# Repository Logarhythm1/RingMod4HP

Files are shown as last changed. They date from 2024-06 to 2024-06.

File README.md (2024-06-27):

# RingMod4HP
CC-By-NC 4.0, 2024 (Non-commercial use permitted)

An AD633-based Ring Modulator in Eurorack format (4HP)

This is based on a design by Roman Sowa, who has kindly allowed me to share this implementation for anyone to build.

Built 1.0 Module Front

It's a great, clean-sounding ring modulator featuring the excellent AD633 IC.
The board is a pretty simple build, with mostly 0603 components. Two footprints are provided for the AD633 IC, and you should choose either DIP or soic package to place. No BOM is provided but it's pretty easy to see what's needed from the schematic. The specific hardware needed is:

- 3 Thonkiconn jacks
- 1 10k vertical 9mm pot
- 2 100k pots
- 2 micromini 3-way switches

Eagle 6 format schematic, board, and panel files are included.

Zip files containing the board and panel gerbers are also included.

Note: Images show the 1.0 version of the board and panel, which have a couple of errors that are corrected in the 1.1 versions presented here. Both were ordered from JLCPCB, with the panel as an "aluminum pcb." The panel came back with white paint and raw aluminum text, which is the inverse of what I expected but it works for me.

Version 1.0 board and panel:

Version 1.0 Board and Panel

Version 1.1 layout:

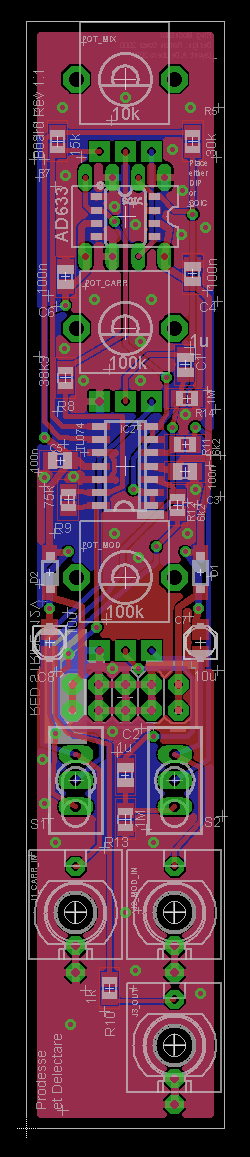
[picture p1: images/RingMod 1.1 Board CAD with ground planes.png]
Version 1.1 board


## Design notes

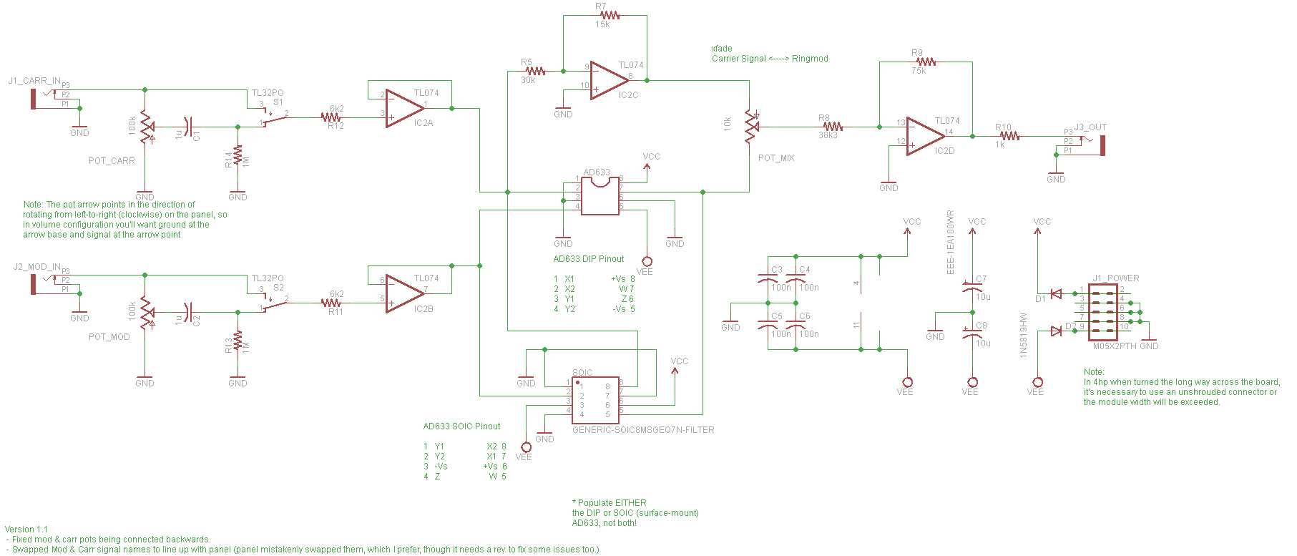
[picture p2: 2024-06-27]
T_RingModSchematic.png

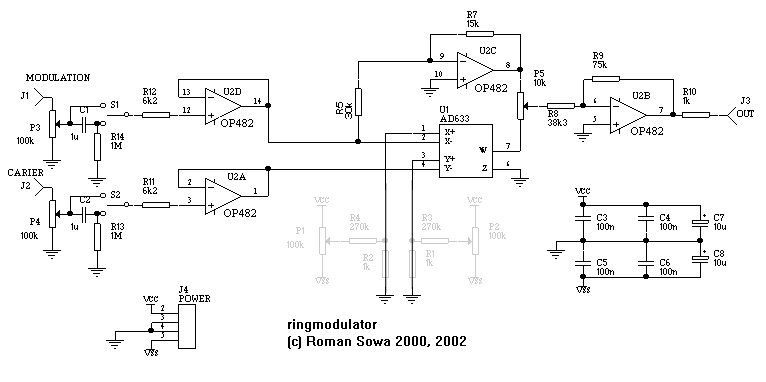
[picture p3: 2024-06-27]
images/Schematic.jpg

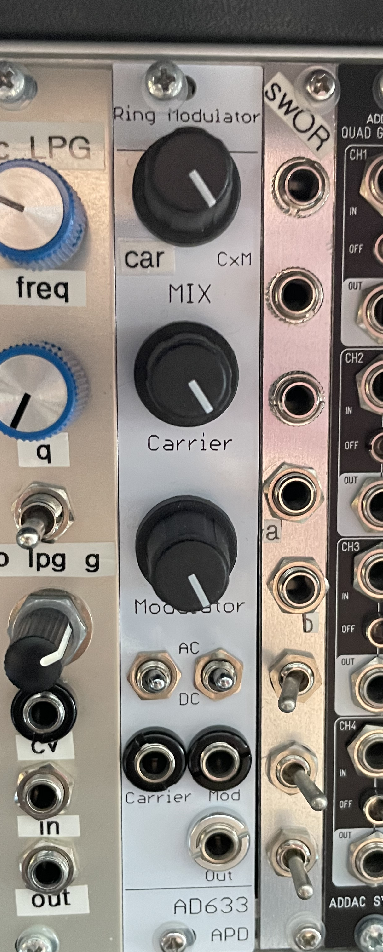
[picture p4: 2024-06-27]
images/Ringmod 1.0 in Rack.png

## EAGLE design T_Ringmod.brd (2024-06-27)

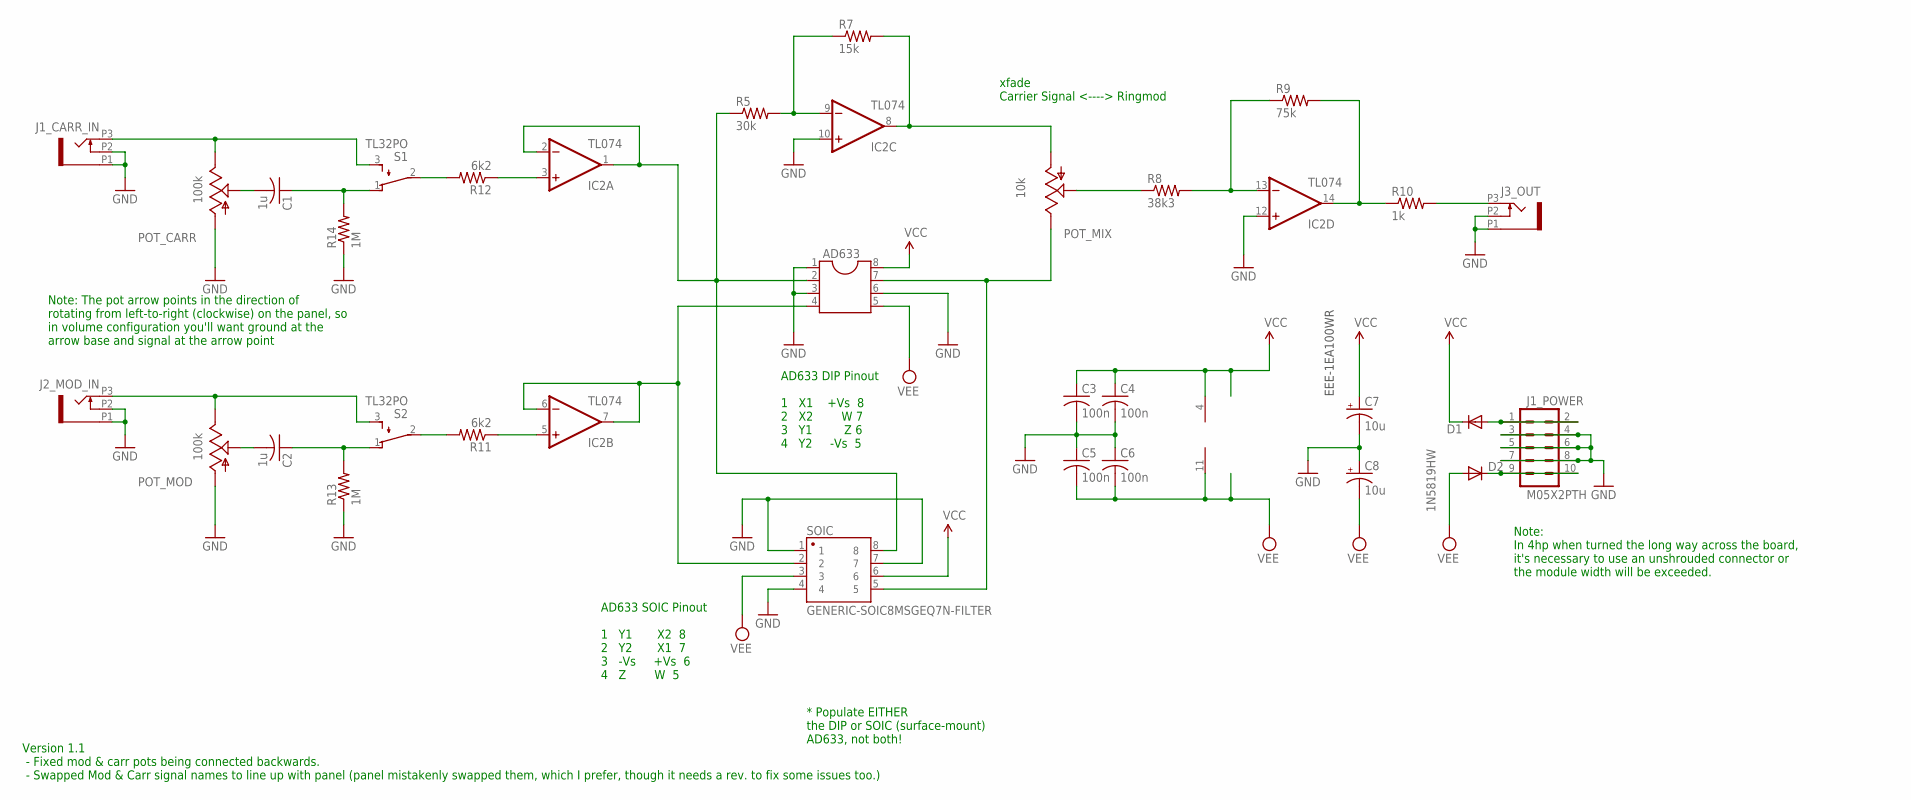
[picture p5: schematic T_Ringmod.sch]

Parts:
AD633: DIL8; DIL08
C1, C2: 1u; C0805
C3, C4, C5, C6: 100n; C0805
C7, C8: 10u; PANASONIC_A
D1, D2: 1N5819HW; SOD123
IC2: TL074; SO14
J1_CARR_IN, J2_MOD_IN, J3_OUT: PJ301_THONKICONN6; WQP_PJ_301M6
J1_POWER: M05X2PTH; AVR_ICSP
POT_CARR: 100k; ALPS_POT_VERTICAL_PS
POT_MIX: 10k; ALPS_POT_VERTICAL_PS
POT_MOD: 100k; ALPS_POT_VERTICAL_PS
R5: 30k; R0805
R7: 15k; R0805
R8: 38k3; R0805
R9: 75k; R0805
R10: 1k; R0805
R11, R12: 6k2; R0805
R13, R14: 1M; R0805
S1, S2: TL32PO; TL3XPO
SOIC: GENERIC-SOIC8MSGEQ7N-FILTER; SO08

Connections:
GND: AD633.1, AD633.3, AD633.6, C3.2, C4.2, C5.1, C6.1, C7.-, C8.+, IC2.10 (+IN), IC2.12 (+IN), J1_CARR_IN.P1 (1), J1_CARR_IN.P2 (2), J1_POWER.3, J1_POWER.4, J1_POWER.5, J1_POWER.6, J1_POWER.7, J1_POWER.8, J2_MOD_IN.P1 (1), J2_MOD_IN.P2 (2), J3_OUT.P1 (1), J3_OUT.P2 (2), POT_CARR.P$3 (A), POT_MOD.P$3 (A), R13.1, R14.1, SOIC.1, SOIC.4, SOIC.7
unnamed: C2.2, POT_MOD.P$2 (S)
unnamed: C1.2, POT_CARR.P$2 (S)
unnamed: C1.1, R14.2, S1.1 (O)
unnamed: R12.2, S1.2
unnamed: IC2.3 (+IN), R12.1
unnamed: D1.A, J1_POWER.1, J1_POWER.2
unnamed: AD633.2, IC2.1 (OUT), IC2.2 (-IN), R5.1, SOIC.8
unnamed: IC2.5 (+IN), R11.1
unnamed: R11.2, S2.2
unnamed: C2.1, R13.2, S2.1 (O)
unnamed: AD633.4, IC2.6 (-IN), IC2.7 (OUT), SOIC.2
unnamed: IC2.9 (-IN), R5.2, R7.1
unnamed: IC2.8 (OUT), POT_MIX.P$3 (A), R7.2
unnamed: AD633.7, POT_MIX.P$1 (E), SOIC.5
unnamed: J2_MOD_IN.P3 (3), POT_MOD.P$1 (E), S2.3 (S)
unnamed: J1_CARR_IN.P3 (3), POT_CARR.P$1 (E), S1.3 (S)
unnamed: POT_MIX.P$2 (S), R8.1
unnamed: IC2.13 (-IN), R8.2, R9.1
unnamed: D2.C, J1_POWER.9, J1_POWER.10
unnamed: IC2.14 (OUT), R9.2, R10.1
unnamed: J3_OUT.P3 (3), R10.2
VCC: AD633.8, C3.1, C4.1, C7.+, D1.C, IC2.4 (V+), SOIC.6
VEE: AD633.5, C5.2, C6.2, C8.-, D2.A, IC2.11 (V-), SOIC.3

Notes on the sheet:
EEE-1EA100WR
AD633 DIP Pinout 1 X1 +Vs 8 2 X2 W 7 3 Y1 Z 6 4 Y2 -Vs 5
xfade Carrier Signal <----> Ringmod
AD633 SOIC Pinout 1 Y1 X2 8 2 Y2 X1 7 3 -Vs +Vs 6 4 Z W 5
* Populate EITHER the DIP or SOIC (surface-mount) AD633, not both!
Version 1.1 - Fixed mod & carr pots being connected backwards. - Swapped Mod & Carr signal names to line up with panel (panel mistakenly swapped them, which I prefer, though it needs a rev. to fix some issues too.)
Note: The pot arrow points in the direction of rotating from left-to-right (clockwise) on the panel, so in volume configuration you'll want ground at the arrow base and signal at the arrow point
Note: In 4hp when turned the long way across the board, it's necessary to use an unshrouded connector or the module width will be exceeded.

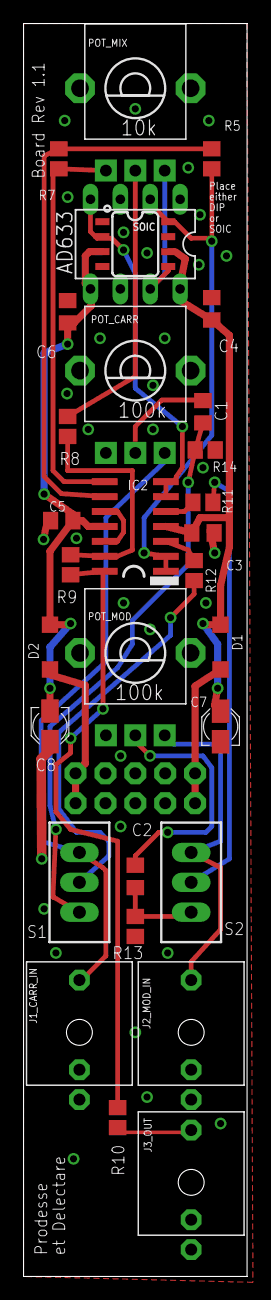
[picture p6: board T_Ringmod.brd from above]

Board: 2 copper layers, 19.0 x 106.5 mm, 31 parts (1 on the bottom side), 24 nets.

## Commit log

2024-06-27 Rev 1.1 Eagle6 files and gerbers in zips
    [T_Ringmod.brd, T_Ringmod.sch, T_Ringmod_PANEL.brd]
2024-06-27 Added image of eagle schematic

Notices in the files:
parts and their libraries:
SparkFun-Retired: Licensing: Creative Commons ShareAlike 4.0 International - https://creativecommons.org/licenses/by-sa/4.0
